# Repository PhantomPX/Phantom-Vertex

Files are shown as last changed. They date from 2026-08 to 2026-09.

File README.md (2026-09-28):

# Phantom-Vertex

<h2>Vertex Mk4.4 Dev Board</h2>

<p align="center">
  <a href="https://github.com/user-attachments/assets/54ca32f1-3a24-44c7-9a8a-99f23128513a">
    PhantomPX Vertex Mk4.4 Pins
  </a>
</p>
      <p>Journey of making my own dev board for studying and general purpose!</p>
      <p>I got interested in making my own electronics stuff. I'm on a quest to fill my room with cool and useful engineering machines. The first step to any great machine is the electronic components inside it. I'm very new to this, so I'm starting off simple.</p>
      <p>My first project will be a super silent (I hope) mechanical keyboard <a href="https://github.com">PhantomBoard</a> powered by Vertex Mk4.4. (On hiatus for now)</p>
      <p> ⚡Powered by STM32F405RGT6 QF64 and the PCB dimensions are 📏24.2*40.6mm (width*height), roughly the size of an adult's thumb 👍</p>
      <p><strong><ins>🚨Note🚨:</ins></strong> I prefer assembling myself so all the PCBs I make <strong><ins>🔴REQUIRE YOU TO SOLDER COMPONENTS YOURSELF🔴</ins></strong>.</p>
      <p>So far, Vertex Mk4.4 is my first and only dev board. More coming soon🙌! (Depends on whether I need different MCUs for future projects.)</p>

## Capabilities
### Microcontroller
- **STM32F405RGT6** (ARM Cortex-M4, up to 168MHz, LQFP64)
- USB Full-Speed 2.0 with onboard ESD protection
- SWD debug header (TC2030-SWD compatible) for programming/debugging
- Reset and bootloader-entry buttons
### Expansion
- 42 GPIO and 14 PWM-capable pins (refer to schematic below & STM32F405RGT6-QF64 datasheet)
- 3 independent I2C buses free for additional sensors/peripherals
- 3 SPI and 2 UART interfaces 

## Vertex Mk4.4 PCB
### Schematic


## BOM

| Item | Parts | Qty. | Unit price (USD) | Price per lot (USD) | Source |
| :--- | :--- | :--- | :--- | :--- | :--- |
| Ceramic capacitor SMD | 33pF 0402 | 2 | 0.0195 | 1.95 | https://www.aliexpress.com/item/1005002960548572.html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 |
| Ceramic capacitor SMD | 10nF 1206 | 1 | 0.0314 | 3.14 | https://www.aliexpress.com/item/1005007176206143.html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 |
| Ceramic capacitor SMD | 100nF 0402 | 7 | 0.0422 | 4.22 | https://www.aliexpress.com/item/1005012522149817.html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 |
| Ceramic capacitor SMD | 1uF 0603 | 1 | 0.0484 | 2.42 | https://www.aliexpress.com/item/1005007160988407.html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 |
| Ceramic capacitor SMD | 2.2uF 0603 | 2 | 0.0672 | 3.36 | https://www.aliexpress.com/item/1005007160988407.html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 |
| Ceramic capacitor SMD | 4.7uF 0402 | 1 | 0.0942 | 4.71 | https://www.aliexpress.com/item/1005012364450156.html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 |
| Ceramic capacitor SMD | 10uF 0805 | 1 | 0.0832 | 4.16 | https://www.aliexpress.com/item/1005008523091680.html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 |
| Ceramic capacitor SMD | 22uF 0805 | 1 | 0.0988 | 4.94 | https://www.aliexpress.com/item/1005008523091680.html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 |
| Ferrite bead SMD |  50mΩ 120Ω@100MHz 2A 0603 | 1 | 0.0116 | 1.16 | https://www.aliexpress.com/item/1005012116787152.html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 |
| USB C receptacle | GCT_USB4085 | 1 | 1.252 | 6.26 | https://www.aliexpress.com/item/1005010442732661.html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 |
| THT male connector | 4(1x2)\|1(1x16)\|1(1x22)\|1(1x5) P1.00mm | - | 1.28 | 2.56 | https://www.aliexpress.com/item/1005006790453916.html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 |
| Ceramic resistor SMD | 5k1 0402 | 2 | 0.0118 | 1.18 | https://www.aliexpress.com/item/1005005982446651.html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 |
| Ceramic resistor SMD | 10k 0402 | 2 | 0.0114 | 1.14 | https://www.aliexpress.com/item/1005005982446651.html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 |
| Ceramic resistor SMD | 1M 0603 | 1 | 0.0148 | 1.48 | https://www.aliexpress.com/item/1005010109041806.html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 |
| Push button SMD | SW_SPST_B3U-1000P | 2 | 0.0146 | 1.46 | https://www.aliexpress.com/item/1005009548875400.html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 |
| Unidirectional ESD SMD | USBLC6-2SC6 | 1 | 0.313 | 3.13 | https://www.aliexpress.com/item/1005007348100430.html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 |
| Low-dropout linear voltage regulator SMD | AMS1117-3.3 | 1 | 0.068 | 0.68 | https://www.aliexpress.com/item/1005008607449037.html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 |
| MCU | STM32F405RGT6 | 1 | 3.15 | 3.15 | https://www.aliexpress.com/item/4000117720745.html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 |
| Crystal oscillator SMD | X322512MSB4SI | 1 | 0.21 | 0.21 | https://www.aliexpress.com/item/1005012668862128.html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 |
| Total+Shipping+Tax | - | - | - | 64.57± | - |

### Footprint & Traces
<table>
  <tr>
    <td>
      vertex mk4 4 ftpt f
    </td>
    <td>
      vertex mk4 4 ftpt b
    </td>
  </tr>
  <tr>
    <td>
     
    </td>
    <td>
      
    </td>
  </tr>
</table>

🔴Red = Top layer (1st)

🔵Blue = Bottom layer (4th)

### 3D View
<table>
  <tr>
    <td>
      vertex mk4 Top
    </td>
    <td>
      vertex mk4 Bottom
    </td>
  </tr>
  <tr>
    <td>
      vertex mk4 Side3
    </td>
    <td>
      vertex mk4 Side4
    </td>
  </tr>
</table>

## Check out my other stuff
[HERE](https://github.com/PhantomPX/Phantom-Dev-Boards)

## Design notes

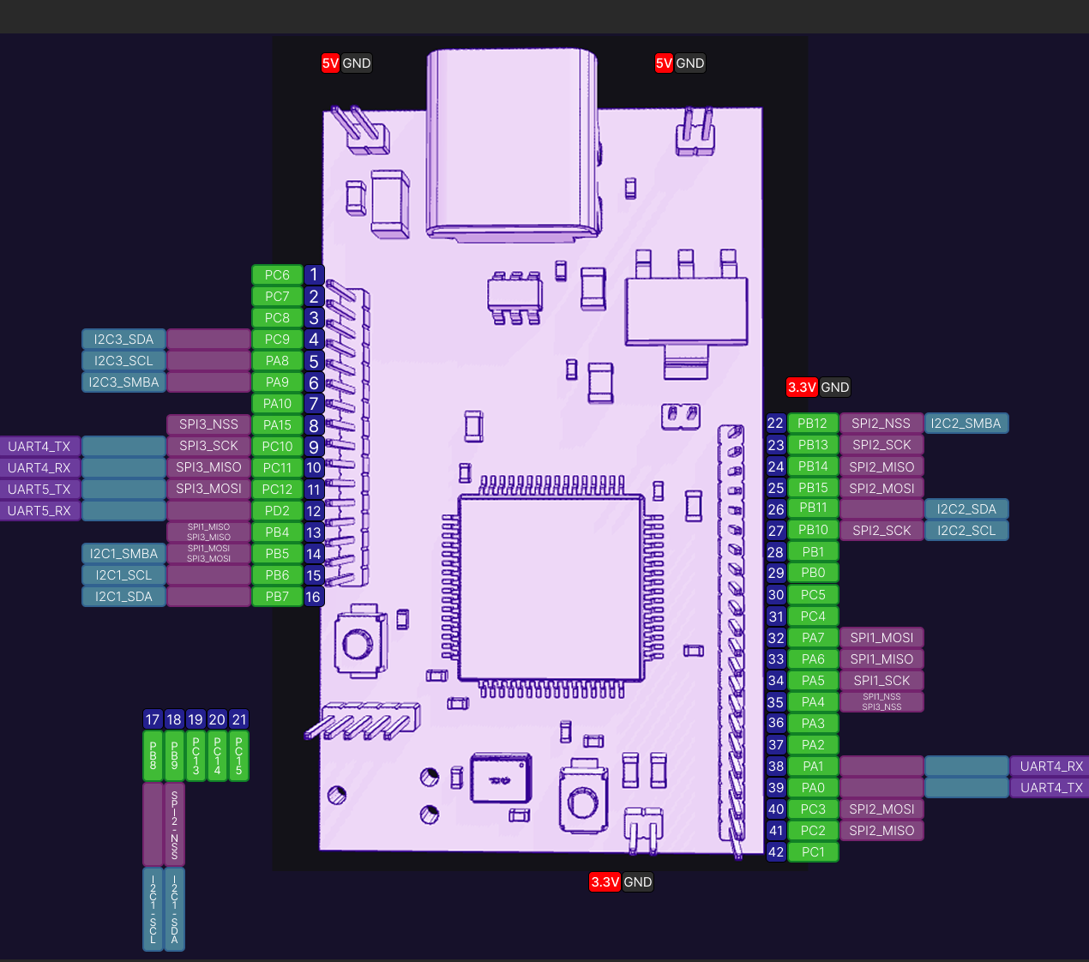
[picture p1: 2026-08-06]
Docs/PhantomPX Vertex Mk4.4 Pins.png

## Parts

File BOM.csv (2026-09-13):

Item | Parts | Qty. | Unit price(USD) | Price per lot(USD) | Source
Ceramic capacitor SMD | 33pF 0402 | 2 | 0.0195 | 1.95 | https://www.aliexpress.com/item/1005002960548572.html
Ceramic capacitor SMD | 10nF 1206 | 1 | 0.0314 | 3.14 | https://www.aliexpress.com/item/1005007176206143.html
Ceramic capacitor SMD | 100nF 0402 | 7 | 0.0422 | 4.22 | https://www.aliexpress.com/item/1005012522149817.html
Ceramic capacitor SMD | 1uF 0603 | 1 | 0.0484 | 2.42 | https://www.aliexpress.com/item/1005007160988407.html
Ceramic capacitor SMD | 2.2uF 0603 | 2 | 0.0672 | 3.36 | https://www.aliexpress.com/item/1005007160988407.html
Ceramic capacitor SMD | 4.7uF 0402 | 1 | 0.0942 | 4.71 | https://www.aliexpress.com/item/1005012364450156.html
Ceramic capacitor SMD | 10uF 0805 | 1 | 0.0832 | 4.16 | https://www.aliexpress.com/item/1005008523091680.html
Ceramic capacitor SMD | 22uF 0805 | 1 | 0.0988 | 4.94 | https://www.aliexpress.com/item/1005008523091680.html
Ferrite bead SMD | 50mΩ 120Ω@100MHz 2A 0603 | 1 | 0.0116 | 1.16 | https://www.aliexpress.com/item/1005012116787152.html
USB C receptacle | GCT_USB4085 | 1 | 1.252 | 6.26 | https://www.aliexpress.com/item/1005010442732661.html
THT male connector | 4(1x2)|1(1x16)|1(1x22)|1(1x5) P1.00mm | - | 1.28 | 2.56 | https://www.aliexpress.com/item/1005006790453916.html
Ceramic resistor SMD | 5k1 0402 | 2 | 0.0118 | 1.18 | https://www.aliexpress.com/item/1005005982446651.html
Ceramic resistor SMD | 10k 0402 | 2 | 0.0114 | 1.14 | https://www.aliexpress.com/item/1005005982446651.html
Ceramic resistor SMD | 1M 0603 | 1 | 0.0148 | 1.48 | https://www.aliexpress.com/item/1005010109041806.html
Push button SMD | SW_SPST_B3U-1000P | 2 | 0.0146 | 1.46 | https://www.aliexpress.com/item/1005009548875400.html
Unidirectional ESD SMD | USBLC6-2SC6 | 1 | 0.313 | 3.13 | https://www.aliexpress.com/item/1005007348100430.html
Low-dropout linear voltage regulator SMD | AMS1117-3.3 | 1 | 0.068 | 0.68 | https://www.aliexpress.com/item/1005008607449037.html
MCU | STM32F405RGT6 | 1 | 3.15 | 3.15 | https://www.aliexpress.com/item/4000117720745.html
Crystal oscillator SMD | X322512MSB4SI | 1 | 0.21 | 0.21 | https://www.aliexpress.com/item/1005012668862128.html
Total+Shipping+Tax | - | - | - | 64.57± | -

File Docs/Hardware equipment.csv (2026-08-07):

Tools | Purpose | Qty. | Price(USD) | Source
Soldering station/Hot air work station/Hot plate | Solder SMD onto PCB | as needed | - | -
Solder/Solder paste | Connects SMD to PCB physically and electrically | as needed | - | -
Flux | Makes soldering waaaay easier | as needed | - | -
Soldering iron tips | To solder diffrent components nicely | 1 | 3.50 | https://www.aliexpress.com/item/1005012511464287.html
TC2030 connector | Debugging microcontroller if everything goes badly | 1 | 13.76 | https://www.aliexpress.com/item/1005012623989528.html
Fume extractor | No YUMMY cancer thanks! | i don't mind | - | -
Magnifying glass station | Very smol SMD components used | 1 | 4.16 | https://www.aliexpress.com/item/1005012238185136.html

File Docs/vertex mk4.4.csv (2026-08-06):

Reference | Qty | Value | DNP | Exclude from BOM | Exclude from Board | Footprint | Datasheet
C1 | 1 | 1uF |  |  |  | Capacitor_SMD:C_0603_1608Metric | https://www.lcsc.com/datasheet/lcsc_datasheet_2304140030_Samsung-Electro-Mechanics-CL10A105KB8NNNC_C15849.pdf
C2 | 1 | 4.7uF |  |  |  | Capacitor_SMD:C_0402_1005Metric | https://www.lcsc.com/datasheet/lcsc_datasheet_2304140030_FH--Guangdong-Fenghua-Advanced-Tech-1206B475K500NT_C29823.pdf
C3,C4,C5,C6,C7,C8,C10 | 7 | 100nF |  |  |  | Capacitor_SMD:C_0402_1005Metric | https://www.lcsc.com/datasheet/lcsc_datasheet_2211101700_YAGEO-CC0603KRX7R9BB104_C14663.pdf
C9 | 1 | 10nF |  |  |  | Capacitor_SMD:C_1206_3216Metric_Pad1.33x1.80mm_HandSolder | https://www.lcsc.com/datasheet/lcsc_datasheet_2211101700_YAGEO-CC0603KRX7R9BB104_C14663.pdf
C11,C14 | 2 | 33pF |  |  |  | Capacitor_SMD:C_0402_1005Metric | https://www.lcsc.com/datasheet/lcsc_datasheet_2304140030_FH--Guangdong-Fenghua-Advanced-Tech-0402CG180J500NT_C1549.pdf
C12 | 1 | 10uF |  |  |  | Capacitor_SMD:C_0805_2012Metric | https://www.lcsc.com/datasheet/lcsc_datasheet_2304140030_Samsung-Electro-Mechanics-CL31A106KBHNNNE_C13585.pdf
C13 | 1 | 22uF |  |  |  | Capacitor_SMD:C_0805_2012Metric | https://www.lcsc.com/datasheet/lcsc_datasheet_2304140030_Samsung-Electro-Mechanics-CL31A226KAHNNNE_C12891.pdf
C15,C16 | 2 | 2.2uF |  |  |  | Capacitor_SMD:C_0603_1608Metric | https://www.lcsc.com/datasheet/lcsc_datasheet_2304140030_Samsung-Electro-Mechanics-CL10A225KO8NNNC_C23630.pdf
FB1 | 1 |  |  |  |  | PCM_JLCPCB:FB_0603 | https://www.lcsc.com/datasheet/lcsc_datasheet_2304140030_Murata-Electronics-BLM18PG121SN1D_C14709.pdf
J1 | 1 | USB_C_Receptacle_USB2.0_16P |  |  |  | Connector_USB:USB_C_Receptacle_GCT_USB4085 | https://www.usb.org/sites/default/files/documents/usb_type-c.zip
J2 | 1 | TC2030_SWD |  |  |  | PCM_marbastlib-various:CON_TC2030_outlined
J3 | 1 | Conn_01x05 |  |  |  | Connector_PinHeader_1.00mm:PinHeader_1x05_P1.00mm_Vertical
J4 | 1 | Conn_01x16 |  |  |  | Connector_PinHeader_1.00mm:PinHeader_1x16_P1.00mm_Vertical
J5,J7,J8,J9 | 4 | Conn_01x02 |  |  |  | Connector_PinHeader_1.00mm:PinHeader_1x02_P1.00mm_Vertical
J6 | 1 | Conn_01x22 |  |  |  | Connector_PinHeader_1.00mm:PinHeader_1x22_P1.00mm_Vertical
R1,R2 | 2 | 5k1 |  |  |  | Resistor_SMD:R_0402_1005Metric
R3 | 1 | 1M |  |  |  | Capacitor_SMD:C_0603_1608Metric_Pad1.08x0.95mm_HandSolder
R4,R5 | 2 | 10k |  |  |  | Resistor_SMD:R_0402_1005Metric
SW1,SW2 | 2 | SW_Push |  |  |  | Button_Switch_SMD:SW_SPST_B3U-1000P
U1 | 1 | USBLC6-2SC6 |  |  |  | Package_TO_SOT_SMD:SOT-23-6 | https://www.st.com/resource/en/datasheet/usblc6-2.pdf
U2 | 1 | AMS1117-3.3 |  |  |  | Package_TO_SOT_SMD:SOT-223-3_TabPin2 | http://www.advanced-monolithic.com/pdf/ds1117.pdf
U3 | 1 | STM32F405RGT6 |  |  |  | Package_QFP:LQFP-64_10x10mm_P0.5mm | https://www.st.com/resource/en/datasheet/stm32f405rg.pdf
X1 | 1 | X322512MSB4SI |  |  |  | PCM_JLCPCB:CRYSTAL-SMD_4P-L3.2-W2.5-BL | https://www.lcsc.com/datasheet/lcsc_datasheet_2403291504_YXC-Crystal-Oscillators-X322512MSB4SI_C9002.pdf

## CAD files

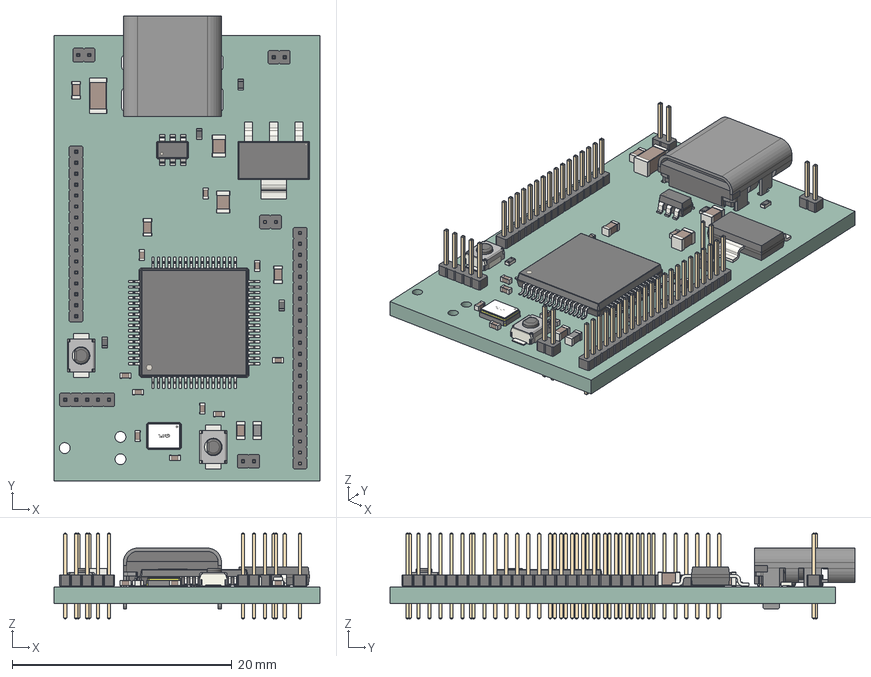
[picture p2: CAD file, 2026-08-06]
3D model/PhantomPX Vertex Mk4.4.step
24.2 x 42.4 x 7.80 mm
PinHeader_1x02_P100mm_Vertical x 4
C_0603_1608Metric x 4
C_0402_1005Metric x 10
C_0805_2012Metric x 2
SOT-23-6
R_0402_1005Metric x 4
L_0603_1608Metric
LQFP-64_10x10mm_P0.5mm
PinHeader_1x22_P100mm_Vertical
USB_C_Receptacle_GCT_USB4085
PinHeader_1x16_P100mm_Vertical
SOT-223
SW_SPST_B3U-1000P x 2
OSC-SMD_4P-L3.2-W2.5-CJ13-320001210A20
C_1206_3216Metric
PinHeader_1x05_P100mm_Vertical
vertex mk4_PCB

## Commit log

2026-08-05 Add files via upload
    File for production. DOES NOT INCLUDE FILES FOR PCBA. ONLY SELF ASSEMBLY!
2026-08-05 Add files via upload
    3D model
    [PhantomPX Vertex Mk4.step]
2026-08-05 Add files via upload
    Files for PCB production. DOES NOT INCLUDE FILE FOR PCBA, ONLY FOR SELF ASSEMBLY!
2026-08-05 Rename PhantomPX Vertex Mk4.4.step to 3D model/PhantomPX Vertex Mk4.4.step
    [PhantomPX Vertex Mk4.4.step]
2026-08-06 Add files via upload
    Production files. DOES NOT INCLUDE FILE FOR PCBA, ONLY FOR SELF-ASSEMBLY!
    [vertex mk4-B_Adhesive.gbr, vertex mk4-B_Cu.gbr, vertex mk4-B_Mask.gbr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]
2026-08-07 Rename vertex mk4.4.csv to docs/vertex mk4.4.csv
    [vertex mk4.4.csv]
2026-08-07 Rename vertex mk4.4.csv to vertex mk4.4.csv
    [vertex mk4.4.csv]
2026-08-07 Create Hardware equipment.csv
    [Hardware equipment.csv]
2026-08-07 Update Hardware equipment.csv
    [Hardware equipment.csv]
2026-09-28 Create Kicad File
2026-09-28 Rename vertex mk4_4.zip to Kicad file/vertex mk4_4.zip
